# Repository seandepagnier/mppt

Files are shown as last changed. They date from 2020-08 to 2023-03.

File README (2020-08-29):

MPPT charge controller for maximum power

- free software and hardware design.  Can be adapted to other requirements.
- all ceramic capacitors.
- buck/boost design allow either higher or lower voltage of battery vs panel.
- components rated for up to 48 volt system (60 volt mosfets)
- voltage and current monitoring on both input and output.
- high-efficiency regulators to power the 3.3v logic as well as the 10v needed for gate drive.

This project uses the stm32duino environment.

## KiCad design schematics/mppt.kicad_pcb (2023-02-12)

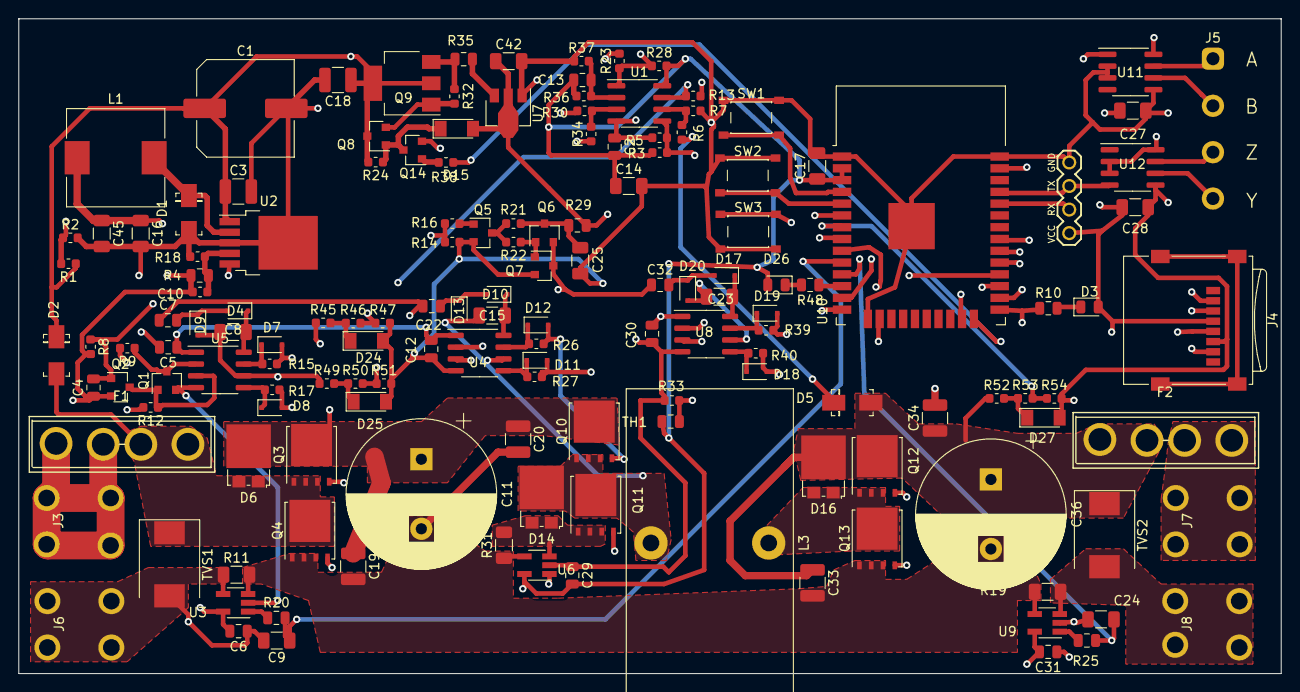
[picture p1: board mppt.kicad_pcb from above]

Board: 4 copper layers, 136.1 x 70.6 mm, 152 parts (0 on the bottom side), 89 nets.

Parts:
C1: 33uF 100v; C_Elec_10x10.2
C2, C6, C7, C13, C22, C32: 100nF; C_0805_2012Metric
C3, C18: 4.7uF; C_1210_3225Metric
C4, C5, C12, C30: 10uF; C_0805_2012Metric
C8, C9, C15, C23, C24, C27, C28, C42: 1uF; C_1206_3216Metric
C10: 33nF; C_0603_1608Metric
C11, C36: 470uF; CP_Radial_D16.0mm_P7.50mm
C14, C16, C17, C25, C45: 10uF; C_1206_3216Metric
C19, C20, C33, C34: 4.7uF 100v; C_1210_3225Metric
C29, C31: 1uF; C_0805_2012Metric
D1, D2, D5: D; DO-214AC
D3: GREEN; LED_0805_2012Metric
D4, D7, D8, D9, D10, D11, D12, D13, D17, D18, D19, D20: D; D_SOD-323F
D6, D14, D16: D_Schottky_AAK; TO-277A
D15, D24, D25, D27: 5.6v; D_MiniMELF
D26: YELLOW; LED_0805_2012Metric
F1, F2: FUSE; BladeFuse-CarType
J2: UART; uart
J3: IN+; screw_terminal
J4: Micro_SD_Card; microSD_HC_Wuerth_693072010801
J5: Conn_01x04; rs422connector
J6: IN-; screw_terminal
J7: OUT+; screw_terminal
J8: OUT-; screw_terminal
L1: 100uH; L_10.4x10.4_H4.8
L3: 100uH; L_Toroid_Vertical_L33.0mm_W17.8mm_P12.70mm_Pulse_KM-5
Q1: Q_NMOS_GDS; SOT-23
Q2: Q_PMOS_GSD; SOT-23
Q3, Q4, Q10, Q11, Q12, Q13: Q_NMOS_GDS; TDSON-8-1
Q5, Q6, Q8, Q14: Q_NPN_BEC; SOT-23
Q7: Q_PNP_BCE; SOT-23
Q9: BCP56; SOT-223-3_TabPin2
R1: 20k; R_0603_1608Metric
R2, R3, R5, R14, R16, R18, R21, R22, R28, R33, R37, R46, R47, R50, R51, R53, R54: 10k; R_0603_1608Metric
R4: 120k; R_0805_2012Metric
R6: 47k; R_0603_1608Metric
R7, R32, R34: 1k; R_0603_1608Metric
R8, R9, R12, R23: 200k; R_0603_1608Metric
R10, R20, R25, R48: 510; R_0805_2012Metric
R11, R19, R31: .001; R_1206_3216Metric
R13, R24, R30, R36, R38: 100k; R_0603_1608Metric
R15, R17, R26, R27, R39, R40: 33; R_0603_1608Metric
R29, R35: 10; R_0805_2012Metric
R45, R49, R52: 333k; R_0603_1608Metric
SW1: page; SW_SPST_PTS810
SW2: menu; SW_SPST_PTS810
SW3: boot; SW_SPST_PTS810
TH1: Thermistor_NTC; R_0805_2012Metric
TVS1, TVS2: TVS; D_SMC
U1: LM393; SOIC-8_3.9x4.9mm_P1.27mm
U2: APE1707H-33-HF; TO-252-5_TabPin3
U3, U6, U9: INA180; SOT-23-5_HandSoldering
U4, U5, U8: lm5109; SO-8_3.9x4.9mm_P1.27mm
U7: AMS1117-5.0; SOT-89-3
U10: ESP32-WROOM-32D; ESP32-WROOM-32
U11, U12: ST485EBDR; SOIC-8_3.9x4.9mm_P1.27mm

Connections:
+3V3: C2.2, C4.1, C6.2, C10.1, C13.2, C14.1, C16.1, C17.1, C27.1, C28.1, C29.2, C31.2, C45.1, D3.2, D26.2, J2.1, J4.4, L1.1, Q2.2, R3.1, R4.1, R8.2, R28.2, R36.1, TH1.1, U1.8, U3.5, U6.5, U9.5, U10.2, U10.3, U11.8, U12.2, U12.3, U12.8
+12V: C5.1, C12.1, C30.1, C42.1, D15.2, R29.1, U4.1, U5.1, U7.2, U8.1
BOOST_H: U8.2, U10.16
BOOST_L: U8.3, U10.14
BUCK_H: U4.2, U10.23
BUCK_L: R23.2, U4.3, U10.13
CHARGE_PUMP: R14.1, R16.2, U10.26
GND: C1.2, C2.1, C3.2, C5.2, C6.1, C9.2, C12.2, C14.2, C16.2, C17.2, C18.2, C24.2, C25.1, C27.2, C28.2, C29.1, C30.2, C31.1, C42.2, C45.2, D1.2, D24.2, D25.2, D27.2, J2.4, J4.6, J6.1, Q1.2, Q5.2, Q7.2, Q14.2, R2.2, R5.2, R7.2, R11.1, R14.2, R18.2, R33.2, R37.1, R47.2, R51.2, R54.2, SW1.1, SW2.1, SW3.2, TVS1.2, U1.4, U2.3, U3.2, U3.4, U4.4, U5.4, U6.2, U7.1, U8.4, U9.2, U10.1, U10.15, U10.38, U10.39, U11.2, U11.3, U11.5, U12.5
HC: C9.1, R20.2, U10.10
HV: R46.2, R47.1, U10.6
IV: R50.2, R51.1, U10.9
LC: C24.1, R25.2, U10.11
LV: R53.2, R54.1, U10.7
unnamed: C1.1, C3.1, C18.1, D2.1, D5.1, Q8.3, Q9.2, R1.1, R6.1, R24.2, U2.1
unnamed: C4.2, Q2.1, R8.1, R13.1, U1.7
unnamed: C7.2, D4.2, D9.1
unnamed: C8.2, D4.1, U5.8
unnamed: C10.2, R4.2, R18.1, U2.4
unnamed: C11.2, C19.2, C20.2, C33.2, C34.2, C36.2, Q4.1, Q13.1, R11.2, R19.2, R31.1, U3.3, U6.4, U9.4
unnamed: C13.1, R36.2, R37.2, U1.2
unnamed: C15.1, D13.2, D14.3, L3.2, Q10.1, Q11.3, U4.6
unnamed: C15.2, D10.1, U4.8
unnamed: C7.1, C22.1, C32.1, Q6.2, Q7.3
unnamed: C22.2, D10.2, D13.1
unnamed: C23.1, D16.1, D16.2, D20.2, L3.1, Q12.1, Q13.3, U8.6
unnamed: C23.2, D17.1, U8.8
unnamed: C25.2, Q6.3, R21.1, R29.2
unnamed: C32.2, D17.2, D20.1
unnamed: D1.1, L1.2, U2.2
unnamed: D3.1, R10.2
unnamed: D7.1, R15.2, U5.7
unnamed: D7.2, Q3.2, R15.1
unnamed: D8.1, R17.2, U5.5
unnamed: D8.2, Q4.2, R17.1
unnamed: D11.1, R27.2, U4.5
unnamed: D11.2, Q11.2, R27.1
unnamed: D12.1, R26.2, U4.7
unnamed: D12.2, Q10.2, R26.1
unnamed: D14.1, D14.2, Q11.1, R31.2, U6.3
unnamed: D15.1, Q8.1, Q14.3, R24.1
unnamed: D18.1, R40.2, U8.5
unnamed: D18.2, Q13.2, R40.1
unnamed: D19.1, R39.2, U8.7
unnamed: D19.2, Q12.2, R39.1
unnamed: D24.1, R45.2, R46.1
unnamed: D25.1, R49.2, R50.1
unnamed: D26.1, R48.2
unnamed: D27.1, R52.2, R53.1
unnamed: F1.1, J3.1
unnamed: F2.2, J7.1
unnamed: J4.2, U10.29
unnamed: J4.3, U10.37
unnamed: J4.5, U10.30
unnamed: J4.7, U10.31
unnamed: J5.1, U11.7
unnamed: J5.2, U11.6
unnamed: J5.3, U12.7
unnamed: J5.4, U12.6
unnamed: J8.1, R19.1, TVS2.2, U9.3
unnamed: Q1.1, Q2.3, R12.1, U5.3
unnamed: Q1.3, R9.1, U5.2
unnamed: Q5.1, R16.1
unnamed: Q5.3, R21.2, R22.2
unnamed: Q6.1, Q7.1, R22.1
unnamed: Q8.2, Q9.1, R32.1
unnamed: Q9.3, R32.2, R35.2
unnamed: Q14.1, R38.1
unnamed: R1.2, R2.1, U2.5
unnamed: R6.2, R7.1, U1.6
unnamed: R10.1, SW3.1, U10.25
unnamed: R3.2, R5.1, R13.2, U1.5
unnamed: R20.1, U3.1
unnamed: R23.1, R28.1, R30.2, U1.1
unnamed: R25.1, U9.1
unnamed: R30.1, R34.2, U1.3
unnamed: R34.1, U6.1
unnamed: R35.1, U7.3
unnamed: R48.1, U10.12
unnamed: SW1.2, U10.4
unnamed: SW2.2, U10.5
PWRDWN: R38.2, U10.24
PWR_H: R9.2, U10.28
PWR_L: R12.2, U10.27
RX: J2.2, U10.34, U11.1
TEMP: R33.1, TH1.2, U10.8
TX: J2.3, U10.35, U12.4
VCC: C33.1, C34.1, C36.1, D5.2, D16.3, F2.1, Q12.3, R52.1, TVS2.1
VDD: C11.1, C19.1, C20.1, D6.3, Q3.3, Q10.3, R45.1
VEE: C8.1, D2.2, D6.1, D6.2, D9.2, F1.2, Q3.1, Q4.3, R49.1, TVS1.1, U5.6

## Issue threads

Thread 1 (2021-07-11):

Hello, have you tested the PCB hardware code for this purpose?

he77PC011, 2021-07-11:
Hello, have you tested the PCB hardware code for this purpose?
stm32duino 2.0
5110 display BL no voltage, the display backlight is not bright

he77PC011, 2021-07-11:
LED D3 pC13 does not light up

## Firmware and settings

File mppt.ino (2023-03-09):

/* Copyright (C) 2023 Sean D'Epagnier <seandepagnier@gmail.com>
 *
 * This Program is free software; you can redistribute it and/or
 * modify it under the terms of the GNU General Public
 * License as published by the Free Software Foundation; either
 * version 3 of the License, or (at your option) any later version.
 */


/* TODO:

real time clock for all logging
app the display and visualize data
update schematic with sync amp on high side for boosting, and isolated power for 100% duty

add hydro mppt algorithms
*/

//#define USE_BT
//#define USE_SD

#ifdef USE_BT

#include "BluetoothSerial.h"

#if !defined(CONFIG_BT_ENABLED) || !defined(CONFIG_BLUEDROID_ENABLED)
#error Bluetooth is not enabled! Please run `make menuconfig` to and enable it
#endif

BluetoothSerial SerialBT;
#endif

#ifdef USE_SD
#include "FS.h"
#include "SD.h"
#endif

float vmppt, duty;


#include <math.h>

const int tempInPin = 32;
const int iddInPin = 25;
const int iccInPin = 26;
const int vddInPin = 34;
const int vccInPin = 35;

const int pwrdwnPin = 2; // turn off 12v

const int buck_lPin = 14;
const int buck_hPin = 15;
const int boost_lPin = 12;
const int boost_hPin = 13;

const int ledPin = 27;

int minVoltage = 7;
int maxVoltage = 32;
int maxInputCurrent = 7;
float startVoltage = 13.4f;
float endVoltage = 13.8f;

#include "driver/mcpwm.h"
#include "soc/mcpwm_reg.h"
#include "soc/mcpwm_struct.h"



void setupSD() {
#ifdef USE_SD
    if(!SD.begin()){
        Serial.println("Card Mount Failed");
        return;
    }
  
    uint8_t cardType = SD.cardType();

    if(cardType == CARD_NONE){
        Serial.println("No SD card attached");
        return;
    }

    Serial.print("SD Card Type: ");
    if(cardType == CARD_MMC){
        Serial.println("MMC");
    } else if(cardType == CARD_SD){
        Serial.println("SDSC");
    } else if(cardType == CARD_SDHC){
        Serial.println("SDHC");
    } else {
        Serial.println("UNKNOWN");

        uint64_t cardSize = SD.cardSize() / (1024 * 1024);
        Serial.printf("SD Card Size: %lluMB\n", cardSize);
        Serial.printf("Total space: %lluMB\n", SD.totalBytes() / (1024 * 1024));
        Serial.printf("Used space: %lluMB\n", SD.usedBytes() / (1024 * 1024));
    }
#endif
}

void log(const char *message)
{
    Serial.println(message);
    Serial.flush();
#ifdef USE_BT
    for(const char *c = message; *c; c++)
        SerialBT.write(*c);
#endif
}

void writedata(const char *message) {
#ifdef USE_SD
    static char buffer[8192];
    strncat(buffer, message, 256);
    if(strlen(buffer) < sizeof buffer - 256)
        return;

    fs::FS &fs = SD;
    const char * path = "log.txt";
    Serial.printf("Appending to file: %s\n", path);

    File file = fs.open(path, FILE_APPEND);
    if(!file) {
        Serial.println("Failed to open file for appending");
        buffer[0] = 0;
        return;
    }
    if(!file.print(buffer))
        Serial.println("Append failed");

    file.close();
    buffer[0] = 0;
#endif
}


enum {IDLE, STANDBY, MPPT} state = IDLE;

float readVoltage(int pin) {
    int sensorValue = analogRead(pin);
    return 3.3*sensorValue/4096*350/10*1.45;
}

float readCurrent(int pin) {
    int sensorValue = analogRead(pin);
    return 3.3 * sensorValue * 10 / 4096;
}

float readTemperature() {
    int x = analogRead(tempInPin)+140;
    float r = 4096.0/x-1;
    float T = 1.0 / (1.0 / 298.0 + 1/3905.0 * log(r)) - 273.0;
    return T;
}


float vcc, vdd, icc, idd, temperature;
long lastt, ttotal;
unsigned long statechange = millis();

/*
Current ripple or max current in discontinuous buck mode
    current_max = duty / frequency / inductance * (vdd - vcc)

at continous/discontinuous point
    duty = vcc / vdd

in discontinuous mode,  this is the max current in the inductor

to solve the time to discharge inductor
    time_dis = current * inductance / vcc

at discontinuous point
    time = (1-duty)/frequency

for off time (diode conducting)
    time_dis = duty / frequency * (vdd/vcc - 1)


for boost dicontinuous mode
   current_max = duty/frequency/inductance*vdd

at discontinuous point
   duty = 1-vdd/vcc

   time_dis = current * inductance / (vcc - vdd)
   time_dis = duty/frequency  / (vcc/vdd-1)

*/
float minduty()
{
    if(vcc > vdd)
        return 1 - vdd / vcc;
    else
        return vcc / vdd - 1;

//    duty += .1; // add some margin to ensure forward transfer
}

float maxduty()
{
    // dont boost more than 4x input or up to max voltage
    return min(1 - vdd/maxVoltage, .75f);
}

void control_log(const char *message)
{
    Serial.print("status: ");
    Serial.println(message);
}

void idle(const char *reason)
{
    if(state == IDLE)
        return;

    pinMode(pwrdwnPin, OUTPUT);
    digitalWrite(pwrdwnPin, HIGH);

    delay(1);
    mcpwm_set_signal_low(MCPWM_UNIT_0, MCPWM_TIMER_0, MCPWM_OPR_A);

    mcpwm_set_signal_low(MCPWM_UNIT_1, MCPWM_TIMER_1, MCPWM_OPR_A);
    mcpwm_set_signal_low(MCPWM_UNIT_1, MCPWM_TIMER_1, MCPWM_OPR_B);
    mcpwm_stop(MCPWM_UNIT_0, MCPWM_TIMER_0);
    mcpwm_stop(MCPWM_UNIT_1, MCPWM_TIMER_1);

    state = IDLE;
    Serial.print("STATE: idle: ");
    Serial.println(reason);
}

void controlloop()
{
    int laststate = state;
    
    if(vcc > maxVoltage)
        idle("Output over voltage");
    else if(vdd > maxVoltage)
        idle("Input over voltage");
    else if(idd > maxInputCurrent)
       idle("Output over current");
    else if(icc > maxInputCurrent)
        idle("Input over current");
    else if(vcc > endVoltage)
        idle("Reached end voltage");
    else if(vcc < minVoltage || vdd < minVoltage)
        idle("min voltage");

    float min_duty = minduty(), max_duty = maxduty();
    if(max_duty - min_duty < .2)
      idle("insufficient duty range");
    
    switch(state) {
    case IDLE:
        pinMode(buck_hPin, OUTPUT);
        digitalWrite(buck_hPin, LOW);
        pinMode(buck_lPin, OUTPUT);
        digitalWrite(buck_lPin, LOW);

        digitalWrite(ledPin, HIGH); // turn LED off

        if(millis() - statechange > 2000) {
            if(vdd < minVoltage || vcc > startVoltage) {
                const unsigned long long uS_TO_S_FACTOR = 1000000ULL;
                esp_sleep_enable_timer_wakeup(10 * uS_TO_S_FACTOR);
                if(vdd < minVoltage)
                    control_log("insufficient input voltage");
                else {
                    control_log("output voltage exceeds start voltage");
                    Serial.print(vcc);
                    Serial.print(" > ");
                    Serial.println(startVoltage);
                }

                control_log("going to sleep now");
                esp_deep_sleep_start();
            } else if(vcc < startVoltage) {
                state = STANDBY; // otherwise turn on
                control_log("STATE: standby");
            }
        }
        
        delay(20);
        break;

    case STANDBY:
        digitalWrite(ledPin, LOW); // turn LED ON

        pinMode(pwrdwnPin, OUTPUT);
        digitalWrite(pwrdwnPin, LOW); // turn on 12v power

        // charge bootstrap
        delay(1);
        digitalWrite(buck_lPin, HIGH);
        delay(1);

        vmppt = (vdd+vcc)/2;
        if(millis() - statechange > 3000) {
            control_log("STATE: mppt");
            duty = minduty();
            state = MPPT;

            digitalWrite(buck_lPin, LOW);

            // setup up pwm output
            mcpwm_gpio_init(MCPWM_UNIT_0, MCPWM0A, buck_hPin);
            //mcpwm_gpio_init(MCPWM_UNIT_0, MCPWM0B, buck_lPin);

            mcpwm_gpio_init(MCPWM_UNIT_1, MCPWM1A, boost_hPin);
            mcpwm_gpio_init(MCPWM_UNIT_1, MCPWM1B, boost_lPin);
            

//            mcpwm_group_set_resolution(MCPWM_UNIT_0, 80000000);
//            mcpwm_timer_set_resolution(MCPWM_UNIT_0, MCPWM_TIMER_0, 10000000);

            // use 40khz frequency
            mcpwm_config_t pwm_config;
            pwm_config.frequency = 20000;
            pwm_config.cmpr_a = 0;
            pwm_config.cmpr_b = 0;
            pwm_config.counter_mode = MCPWM_UP_COUNTER;
            pwm_config.duty_mode = MCPWM_DUTY_MODE_0;

            // setup deadtime to ensure both transistors are off
            // 3 is 3x100ns    The transistors appear to switch in 100ns
            mcpwm_deadtime_enable(MCPWM_UNIT_1, MCPWM_TIMER_1, MCPWM_ACTIVE_HIGH_COMPLIMENT_MODE, 3, 3);
        
            mcpwm_init(MCPWM_UNIT_0, MCPWM_TIMER_0, &pwm_config);   //Configure PWM0A & PWM0B with above


            pwm_config.frequency = 2000;
            pwm_config.cmpr_a = 0;
            pwm_config.cmpr_b = 0;
            pwm_config.counter_mode = MCPWM_UP_COUNTER;
            pwm_config.duty_mode = MCPWM_DUTY_MODE_0;
            mcpwm_init(MCPWM_UNIT_1, MCPWM_TIMER_1, &pwm_config);   //Configure PWM0A & PWM0B with above            

            mcpwm_start(MCPWM_UNIT_0, MCPWM_TIMER_0);
            mcpwm_start(MCPWM_UNIT_1, MCPWM_TIMER_1);
            
            mcpwm_set_duty(MCPWM_UNIT_0,MCPWM_TIMER_0,MCPWM_OPR_A,0);
            //mcpwm_set_duty(MCPWM_UNIT_0,MCPWM_TIMER_0,MCPWM_OPR_B,99);
            
            mcpwm_set_duty(MCPWM_UNIT_1,MCPWM_TIMER_1,MCPWM_OPR_A,0);
            mcpwm_set_duty(MCPWM_UNIT_1,MCPWM_TIMER_1,MCPWM_OPR_B,0);
        }
        break;

    case MPPT:
    {
        float err = (vdd - vmppt);
        duty += .0005 * err; // adjust duty to follow mppt voltage

        if(idd > maxInputCurrent)
            duty -= .1 * (idd - maxInputCurrent);

        duty = min(max(duty, min_duty), max_duty);


        if(duty < -.01) {
            mcpwm_set_duty(MCPWM_UNIT_0,MCPWM_TIMER_0,MCPWM_OPR_A,100*(1+duty));
            //mcpwm_set_duty(MCPWM_UNIT_0,MCPWM_TIMER_0,MCPWM_OPR_B,0);

            mcpwm_set_duty(MCPWM_UNIT_1,MCPWM_TIMER_1,MCPWM_OPR_A,99.5);
            mcpwm_set_duty(MCPWM_UNIT_1,MCPWM_TIMER_1,MCPWM_OPR_B,99.5);
        } else if(duty > .01) {
            // for now not boosting
            if(duty > 0)
                duty = 0;

            //mcpwm_set_duty(MCPWM_UNIT_0,MCPWM_TIMER_0,MCPWM_OPR_A,99);
            //mcpwm_set_duty(MCPWM_UNIT_0,MCPWM_TIMER_0,MCPWM_OPR_B,0);

            //mcpwm_set_duty(MCPWM_UNIT_1,MCPWM_TIMER_1,MCPWM_OPR_A,0);
            //mcpwm_set_duty(MCPWM_UNIT_1,MCPWM_TIMER_1,MCPWM_OPR_B,100*duty);
        } else {
            // duty is nearly neutral,  just keep both sides on
            mcpwm_set_duty(MCPWM_UNIT_0,MCPWM_TIMER_0,MCPWM_OPR_A,99);
            //mcpwm_set_duty(MCPWM_UNIT_0,MCPWM_TIMER_0,MCPWM_OPR_B,0);

            //mcpwm_set_duty(MCPWM_UNIT_1,MCPWM_TIMER_1,MCPWM_OPR_A,0);
            //mcpwm_set_duty(MCPWM_UNIT_1,MCPWM_TIMER_1,MCPWM_OPR_B,100*duty);
        }


        static float trackingdir = .1, avgpout, lastpout;
        static int trackingcount = 0;
        if(icc > 0.2)
            if(fabs(vdd-vmppt) < .15 || duty == max_duty || duty == min_duty) {
                float pout = vcc*icc;
                avgpout += pout;
                trackingcount++;
            }

        float pin = vdd*idd, pout = vcc*icc;
        if(trackingcount == 10) {
            avgpout /= trackingcount;
            trackingcount = 0;
            avgpout = 0;

            if(lastpout > avgpout) // change dir
                trackingdir = -trackingdir;
            lastpout = avgpout;

            if(duty == max_duty) {
                trackingdir = fabs(trackingdir);
                Serial.println("max duty mppt");
            } else if(duty == min_duty) {
                trackingdir = -fabs(trackingdir);
                Serial.println("min duty mppt");
            }

            vmppt += trackingdir; // update voltage set point


            if(duty >= 0)
                idle("Buck mode only!");
        }
    }  break;
    }
    
    if(temperature > 45)
        idle("OverTemperature");

    if(state != laststate)
        statechange = millis();
}

int global_samplecount;
void control(void *param)
{
    unsigned long t0 = millis();
    const int loop_period = 100;
    for(;;) {
        int samplecount = 0;
        float vcc_in = 0, vdd_in = 0, icc_in = 0, idd_in = 0;
        float temperature_in = 0;
        while(samplecount < 10 || millis()-t0 < loop_period - 10) {
            vcc_in+=readVoltage(vccInPin);
            vdd_in+=readVoltage(vddInPin);
            icc_in+=readCurrent(iccInPin);
            idd_in+=readCurrent(iddInPin);

            samplecount++;
        }

        temperature_in = readTemperature();

        temperature = temperature*.95+temperature_in*.05;
        
        global_samplecount = samplecount;

        vcc = vcc_in / samplecount;
        vdd = vdd_in / samplecount;
        icc = icc_in / samplecount;
        idd = idd_in / samplecount;
        
        controlloop();
        unsigned long t1 = millis();
        ttotal = t1 - t0;

        if(ttotal < loop_period) {
            unsigned long dt = ttotal > loop_period ? loop_period : ttotal;
            const TickType_t xDelay = (loop_period - ttotal) / portTICK_PERIOD_MS;
            vTaskDelay( xDelay );
            t0 += loop_period;
        } else
            t0 = t1;
    }
}

TaskHandle_t Control;                 //SYSTEM PARAMETER  - Used for the ESP32 dual core operation
void setup() {

#ifdef USE_BT
    SerialBT.begin("mppt-node"); //Bluetooth device name
#endif
    Serial.begin(115200);

    setupSD();

    pinMode(pwrdwnPin, OUTPUT);
    digitalWrite(pwrdwnPin, HIGH);
    
    // initialize serial communications
    pinMode(ledPin, OUTPUT);
    digitalWrite(ledPin, HIGH);


    int sketchsize = ESP.getSketchSize();
    delay(100);
    uint64_t fusemac = ESP.getEfuseMac();
    uint8_t* chipid = (uint8_t*) & fusemac;
    char mac[20];
    snprintf(mac, sizeof mac, "%02x:%02x:%02x:%02x:%02x:%02x", chipid[0], chipid[1], chipid[2], chipid[3], chipid[4], chipid[5]);
    Serial.print("mac ");
    Serial.println(mac);

    xTaskCreatePinnedToCore(control,"control",10000,NULL,9/*priority*/,&Control,0);

    delay(200);
}


void loop()
{
    char buf[256];
    float pin = vdd*idd, pout = vcc*icc;
    float efficiency;
    if(pin)
        efficiency = pout / pin * 100.0f;
    else
        efficiency = 0;

    if(vcc || vdd) {
        sprintf(buf, "mppt (%.2fV %.2fA %.1fW) (%.2fV %.2fA %.1fW) %.4f%% %.2fV %.1fC %.1f%% %ldms %d", vdd, idd, pin, vcc, icc, pout, 100.0f*duty, vmppt, temperature, efficiency, ttotal, global_samplecount);
        log(buf);
    }
//writ_edata(buf);
    //vTaskGetRunTimeStats(buf);

    //Serial.println(buf);

    // Wait for the next cycle.
    const TickType_t xDelay = 1000 / portTICK_PERIOD_MS;
    vTaskDelay( xDelay );
}

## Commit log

2020-08-29 add kicad schematics
    [mppt.kicad_pcb, mppt.sch]
2020-08-30 add option to set backlight on and off for buttons
2020-09-01 improve startup, allow set frequency from buttons
2020-09-02 improve startup
    [mppt.sch]
2023-02-12 update schematic
    [mppt.kicad_pcb, mppt.sch]
2023-03-09 improve schmatics
    [mppt.sch]
